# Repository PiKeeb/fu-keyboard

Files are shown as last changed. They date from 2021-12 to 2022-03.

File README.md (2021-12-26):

# fu-keyboard





**FU!Keyboard** (**Functionally Ultimate Keyboard** or **FUK** for short) is the hotswappable 26x7 ortholinear behemoth of a keyboard with small 0.91" 128x32 OLED display, 4 independent rotary encoders and addressable RGB per-key illumination.

FUK sports the memory-rich **Atmel AT90USB1286** MCU for the native QMK and VIA(L) support (and with that many keys you are gonna need a whole lotta memory for a whole lotta macros, extra keystrokes and all sorts of stuff).

## Features:
1. **Atmel AT90USB1286-MU** MCU with 128 kB of programmable memory
2. **182 MX-type Switches** arranged in full 26x7 ortholinear matrix
3. **Kailh CPG151101S11** hotswappable sockets
4. **SSD1306 0.91" 128x32 OLED** display
5. **4 independent EC11** rotary encoders with switches
5. **182 SK6812MINI-E (or a-likes) addressable RGB LEDs** for per-key illumination
6. **Gasket-mounted case** with unique 1.5 degree typing angle
7. Uses [**ao03-2725's Unified Daughterboard**](https://github.com/ai03-2725/Unified-Daughterboard)

## 3D CAD Renders

FURender 1

FURender 2

FURender 3

FURender 4

FURender 5

## Disclaimers

All the designs and files are provided **"AS IS"** without any warranty or support.

The designs are licensed under [**CC BY-SA 4.0 International Licence**](https://creativecommons.org/licenses/by-sa/4.0/)

**Warning!** This project has not been prototyped as of right now (working on it). Bear that in mind when doing anything with it.

## Project's Folder Structure

- `/case_files` contains the files related to the case design
- `/pcb_files` contains the files related to the PCB design

Each subfolder contains `README.md` file that is useful to read if you'd like to produce or modify the project

## Acknowledgements

- Original idea/inspiration: [u/mxangrytoast](https://www.reddit.com/user/mxangrytoast)
- Logo Font: [Broken15](https://www.dafont.com/broken15.font) by [misprintedtype](http://www.misprintedtype.com)
- Logo uses material [designed by starline / Freepik](http://www.freepik.com)
- PCB designed in [KiCad](https://www.kicad.org)
- Case designed and rendered in [Fusion360](https://www.autodesk.com/products/fusion-360/overview)

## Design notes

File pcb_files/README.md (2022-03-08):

# fu-keyboard/pcb_files

## Folder Structure

- `/bom` contains the Bill of Material for PCB in interactive HTML format
- `/gerber` contains the Gerber files for PCB production
- `/kicad_project` contains the KiСad project files
- `/pcb_3dmodel` contains STEP 3D model of the PCB for with most of the components

**NB:** for opening the project files use the following version of KiCad (or newer):

*Version: (6.0.1-0), release build*

## Possible issues with powering SK6812MINI-E

There are ***182*** SK6812MINI-E RGB LEDs on the PCB that might trip the USB over-current protection on your PC/USB Hub. In that case, it's recommended to lower the maximum brightness of the LEDs **AND** to use the powered USB hub.

It's also possible to power the LEDs using the separate power adapter. To do that, you are going to need **5V 40W (8A)** power supply with the **Barrel jack (OD 4.5mm, ID 1mm, positive polarity)**.

You also need to cut the **JP1** jumper on the back of the PCB in order to use the power adapter:

cut_here

After that's done you can plug the power adapter:

plug here

## PCB Revision History

REV  |  Description
--|--
1.0  |  Open-source Release version
1.0.1  |  Fixed the LEDs

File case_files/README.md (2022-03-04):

# fu-keyboard/case_files

## Folder Structure

- `/dxf` contains the DXF drawings of the gaskets and the key plate
- `/step` contains STEP 3D models of the bottom and the top parts of the case as well as the gaskets and the key plate

## Production instructions

### Case Threads

ALL the threads on the case are standard M2. Threads should go inside the holes as deep as possible.

Threads location on the **bottom** part of the case:
threads_bottom

Threads location on the **top** part of the case:
threads_top

### Gaskets

Gaskets should be made of rubber 2.25-2.40mm thick sheet with the *optional* sticky layer at the bottom.

You would need 78 gaskets for both top and the bottom parts of the case.

### Key plate

Can be made out of any sturdy material with the thickness of 1.5mm.

**Aluminium, FR4, steel, brass, carbon fibre** are all viable options.

## Bill of material for assembly

* 1x **bottom** case part
* 1x **top** case part
* 1x **key plate**
* 1x **FU!Keyboard PCB**
* 1x **Unified Daughterboard PCB**
* 1x **Unified Daughterboard Cable** (**25 cm**)
* 78x **gaskets**
* 1x button head **M2x6** screw
* 4x button head **M2x3** screws
* 31x button head **M2x10** screws

**NB:** When choosing screws, make **absolutely sure** that the head diameter (øD on the picture below) is **NO MORE** than 3.5mm

button_head

## Assembly instructions

1. **Insert gaskets** into all gasket locations on top and bottom parts of the case. Make sure that they are sticking out about 0.25-0.40mm creating the "lip" for the key plate to rest on.

gasket_lips

2. Using the **M2x3** screws, **secure the Unified Daughterboard PCB** to the bottom part of the case
3. **Plug in** one end of Unified Daughterboard **Cable** to the **Unified Daughterboard PCB**
4. **Partly populate the key plate** with a couple of switches in the corners
5. **Plug the key plate** with the switches onto the **FU!Keyboard PCB**
6. **Finish populating the key plate** with the rest of the switches
7. **Plug in the other end** of the Unified Daughterboard **Cable** to the **FU!Keyboard PCB**
8. **Drop the PCB and the key plate assembly** inside the bottom part of the case, making sure that *a)* all the holes on case are lined up with the corresponding ports on the **FU!Keyboard PCB**, and *b)* that the key plate rests on the gasket lips.
9. Using the **M2x10** screws, screw the top and the bottom parts of the case together from the bottom.
10. Use the **M2x6** near the port Power Adapter (*optional*) plugs into

plug here

## Case Revision History

REV  |  Description
--|--
1.0  |  Open-source Release version
1.1  |  Added the **fu_bottom_logo.step** file with the logo on the bottom part of the case

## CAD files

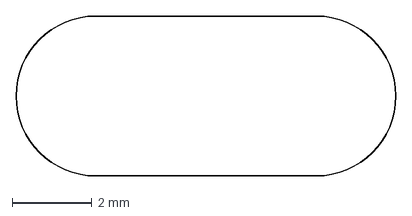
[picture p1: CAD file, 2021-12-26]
case_files/dxf/fu_gasket.dxf
9.50 x 4.00 mm

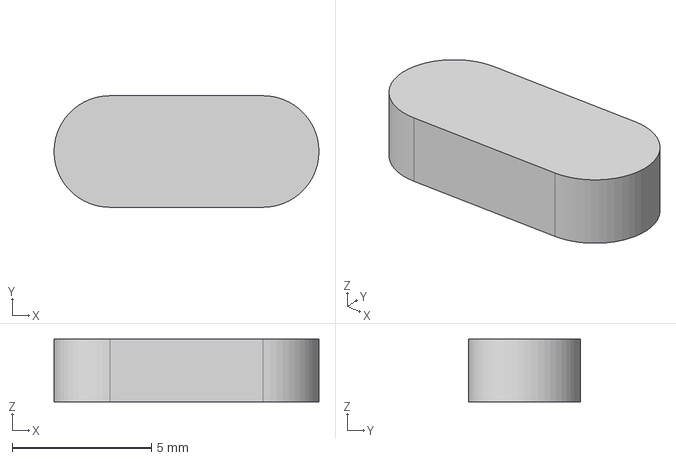
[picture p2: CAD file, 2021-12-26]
case_files/step/fu_rubbergasket.step
9.50 x 4.00 x 2.25 mm

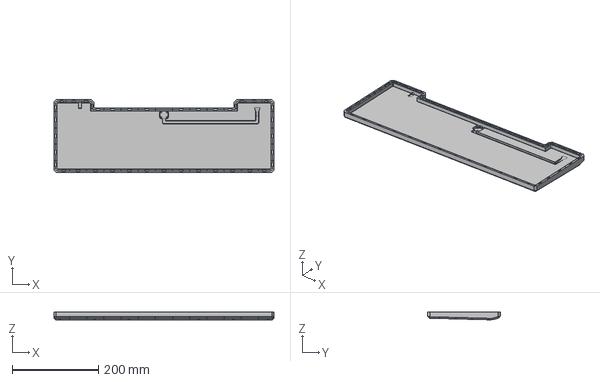
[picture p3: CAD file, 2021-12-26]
case_files/step/fu_bottom.step
511.6 x 168.7 x 17.9 mm

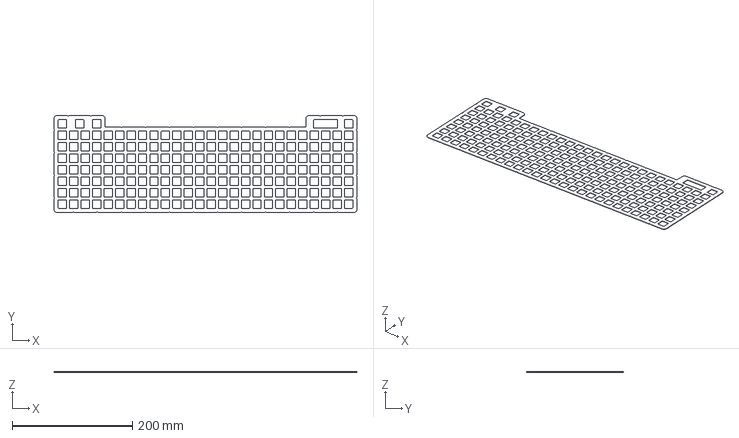
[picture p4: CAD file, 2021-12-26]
case_files/step/fu_keyplate.step
504.2 x 161.3 x 1.50 mm

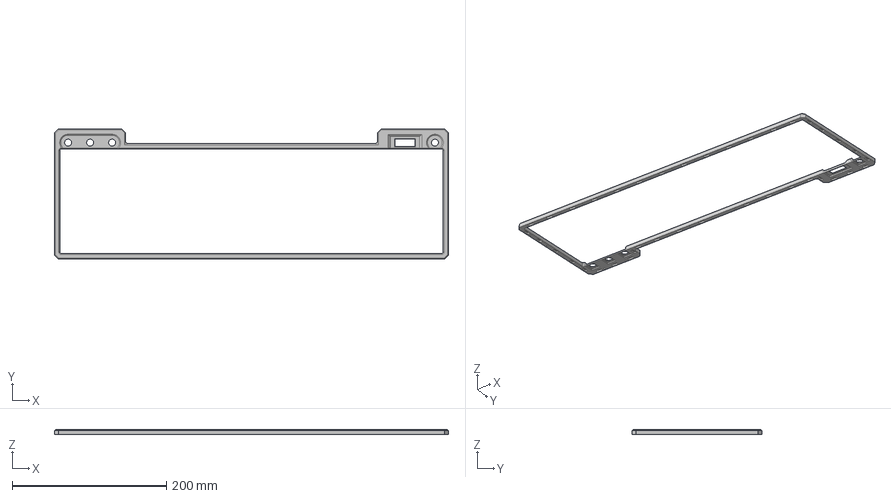
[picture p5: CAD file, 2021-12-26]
case_files/step/fu_top.step
511.6 x 168.7 x 6.80 mm

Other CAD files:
case_files/dxf/fu_keyplate.dxf

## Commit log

2021-12-26 1.0 Release commit
    [fu_bottom.step, fu_gasket.dxf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]
2022-03-04 Added the case w/ logo
2022-03-08 PCB rev 1.0.1 - Fixed the LEDs
